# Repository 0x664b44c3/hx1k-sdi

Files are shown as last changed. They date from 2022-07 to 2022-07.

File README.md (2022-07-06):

# HX1k-SDI
An SDI encoder/serializer on Lattice iCE40 FPGAs

The iCE40 series of FPGAs is low cost and is supported by an opensource toolchain (though not currently used for this project)
The devices are low density and low speed and lack advanced features like SerDes or true LVDS-IO, though.

## Features of the serializer
 * fits multiple times into an 1k gates iCE40 FPGA
 * fpga-vendor agnostic, besides the specific instantiation of the SB_IO for DDR out
 * needs one PLL running at half the bitrate (or at full bitrate if your IO can run at 270MHz)
 * should be extendable to generate DVB-ASI (would need 8B/10B instead of SMPTE scrambler and NRZI)
 * accepts bt.656 video at 27MHz word rate

## Abstract
This project implements an SD-SDI serializer (aka transmitter) completely in fabric, requiring nothing but an unused PLL
that is used to generate a 135MHz from an externally supplied 27MHz sample clock (27MWords/s with CbYCrY 4:2:2 encoding, 
13.5MHz pixel clock).
Most of the logic operates at 27MHz with just the final multiplexer and a DDR-out buffer running at the full 135MHz.

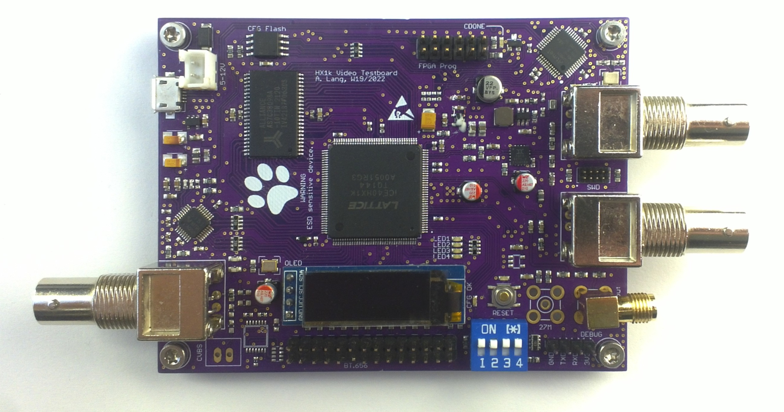
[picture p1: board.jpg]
board


## Features of the test board
 * iCE40HX1k FPGA
 * 27MHz crystal oscillator
 * 10bit bt.656 video port
 * TVP5151 video decoder to test analog to sdi conversion
   * alternatively/additionally an LMH1881 can be fitted
 * 1MByte (512kx16) of SRAM taht can hold one complete frame of interlaced PAL/NTCS
 * ATSAMD21G18 MCU for programming the FPGA config flash and configuring the TVP, can be omitted
 * 4-pin header for I2C 128x32 OLED display
 * FPGA config pins on pinheader to allow flashing the config without a MCU
 * switchmode regulator for the 3.3V rail, allows input voltages of 5 to 12V
* Current functionality in the FPGA demo project
   * Color bars generator
   * SDI pathological pattern generator
   * Analog to SDI converter
   * About half the FPGA is still free for additional functionality

## Scope
This project contains a complete eval board for SDI video generation on
iCE40-HX FPGAs. UP-series might work, too, but it's unclear if the IOB and Fabric are fast enaugh
(might test it on iCEBreaker at some point in time).

## Contents
This project consists of the following subfolders:
 * fpga: the FPGA design (VHDL, iCECube2 project)
 * hardware: The board design (eagle 6), schematic diagrams as PDF
 * firmware: Firmware for the ATSAMD21 MCU that is on the board as well
 * release: synthesized FPGA config, firmware image, gerbers etc

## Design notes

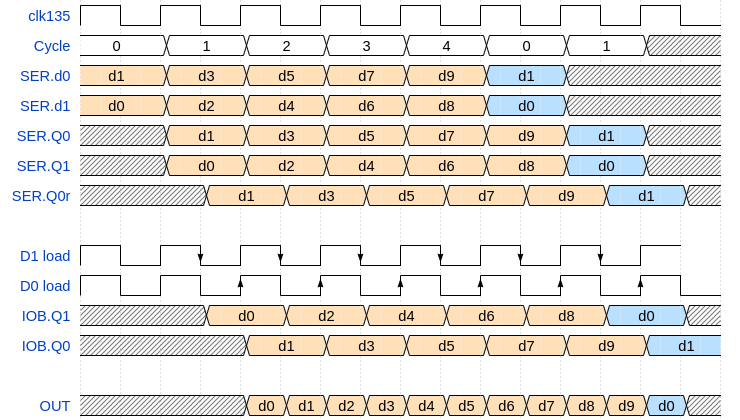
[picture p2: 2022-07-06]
documentation/timings.png

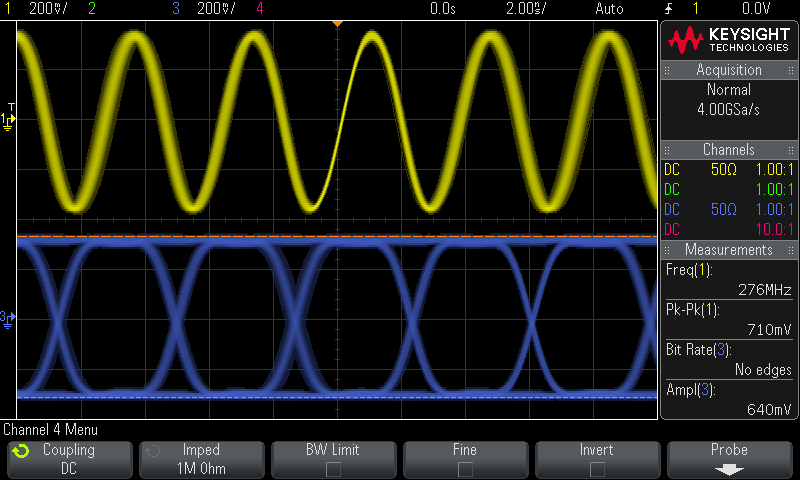
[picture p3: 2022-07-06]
documentation/sdi_eye.png

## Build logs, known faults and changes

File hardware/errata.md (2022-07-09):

# Errata
## Revision 0 (initial release)
 - RAM data pin 6 on global buffer pad that blocks PLL when used
 - footprint of IC7 (NCP115) should have slightly larger pads for easier soldering
 -

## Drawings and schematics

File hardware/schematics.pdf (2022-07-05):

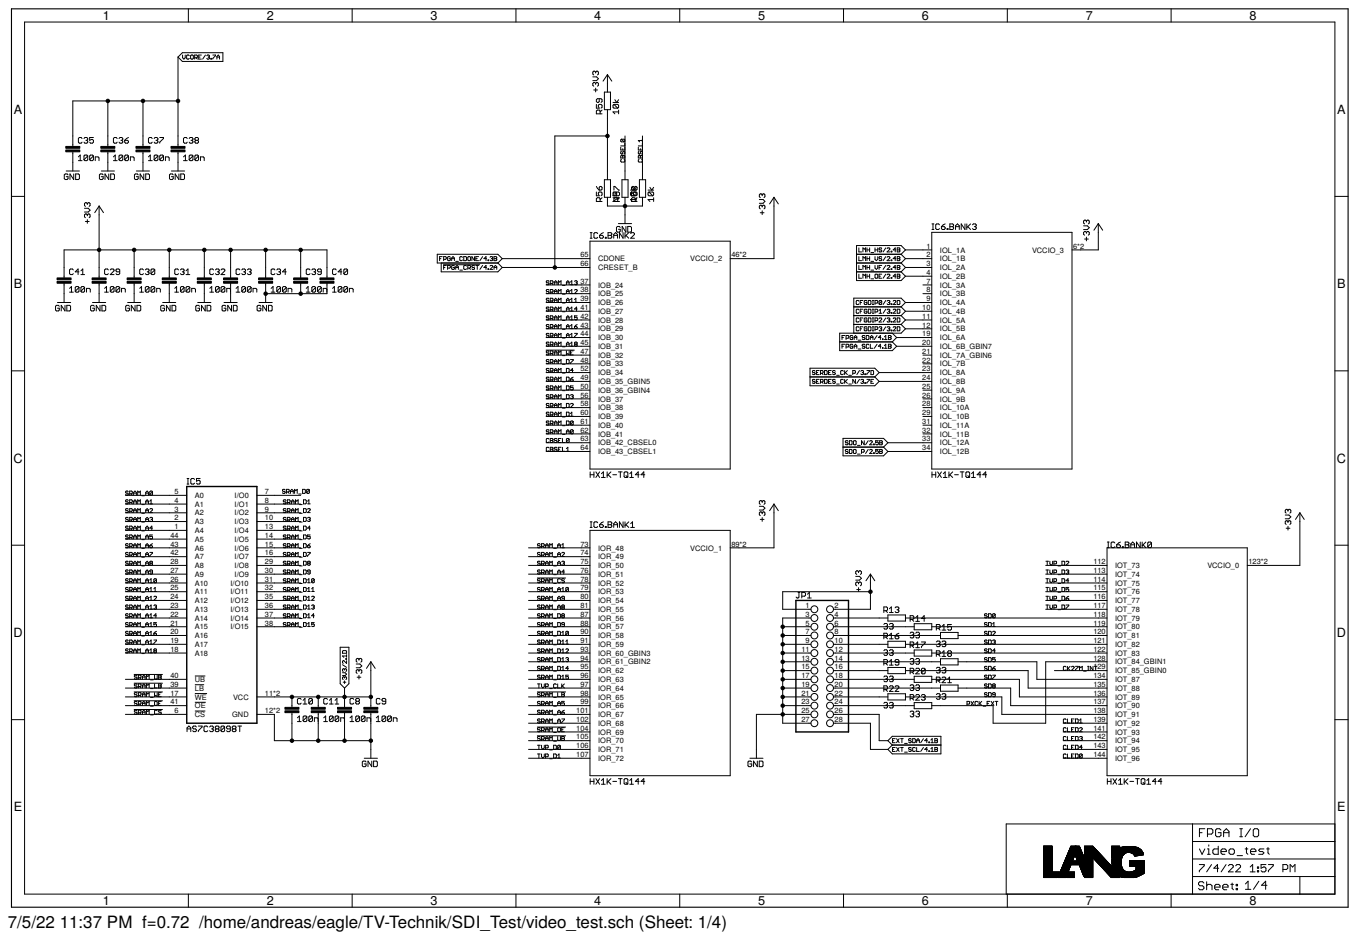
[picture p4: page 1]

7/5/22 11:37 PM f=0.72 /home/andreas/eagle/TV-Technik/SDI_Test/video_test.sch (Sheet: 1/4)

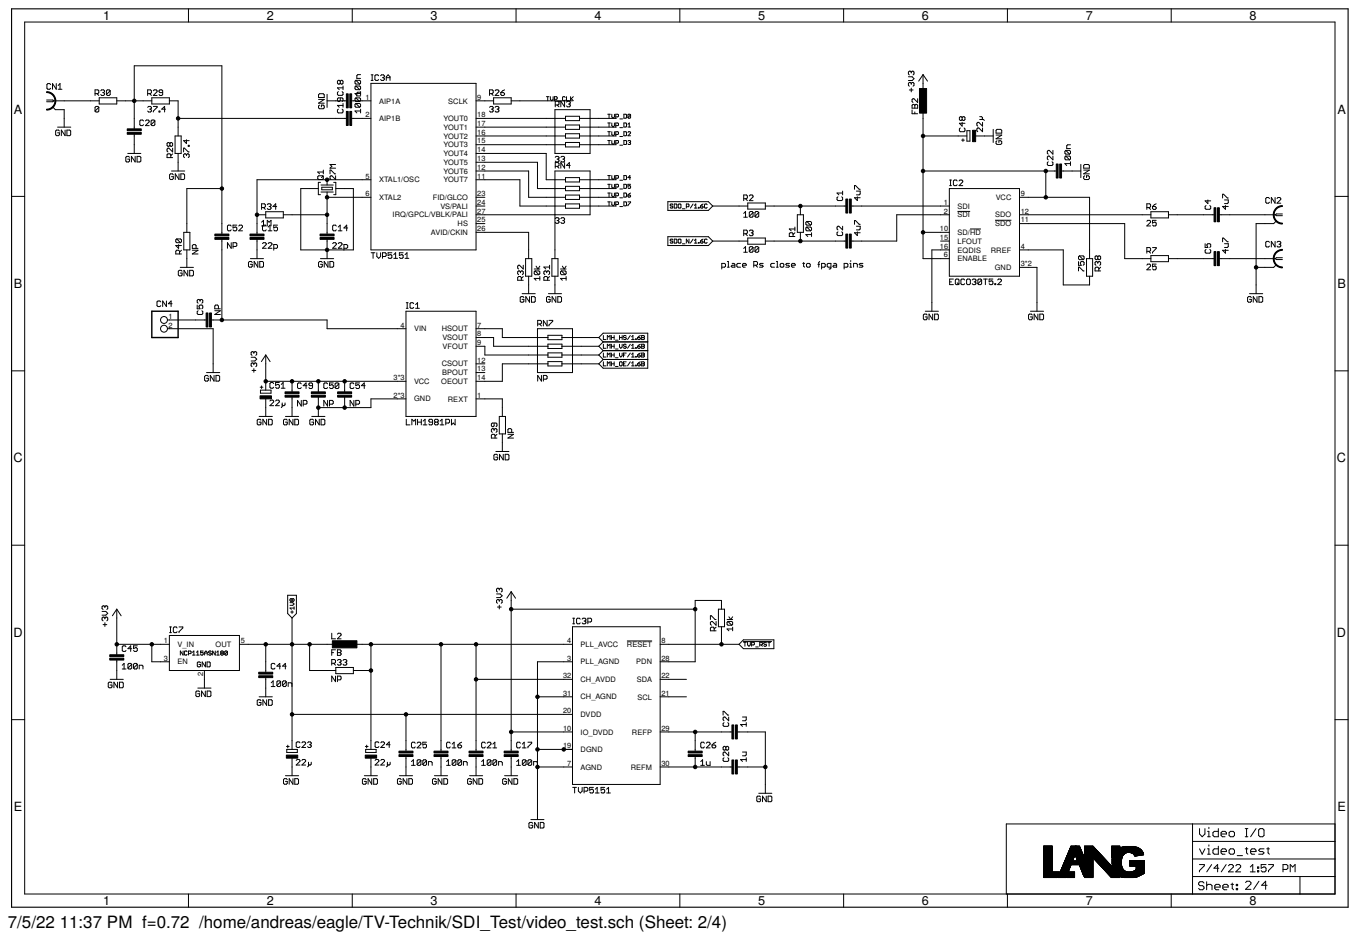
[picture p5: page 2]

7/5/22 11:37 PM f=0.72 /home/andreas/eagle/TV-Technik/SDI_Test/video_test.sch (Sheet: 2/4)

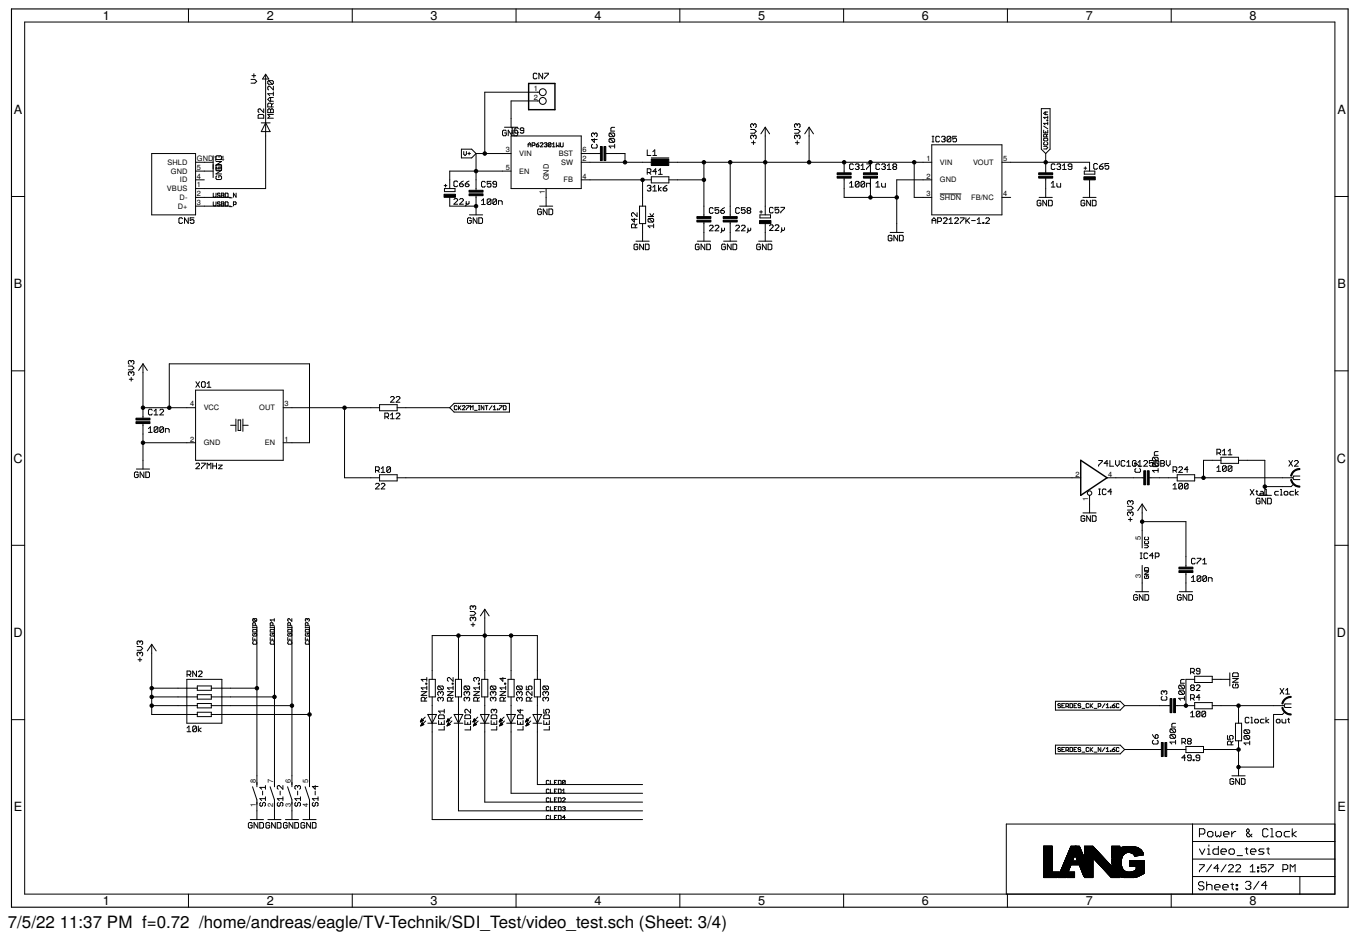
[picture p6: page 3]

7/5/22 11:37 PM f=0.72 /home/andreas/eagle/TV-Technik/SDI_Test/video_test.sch (Sheet: 3/4)

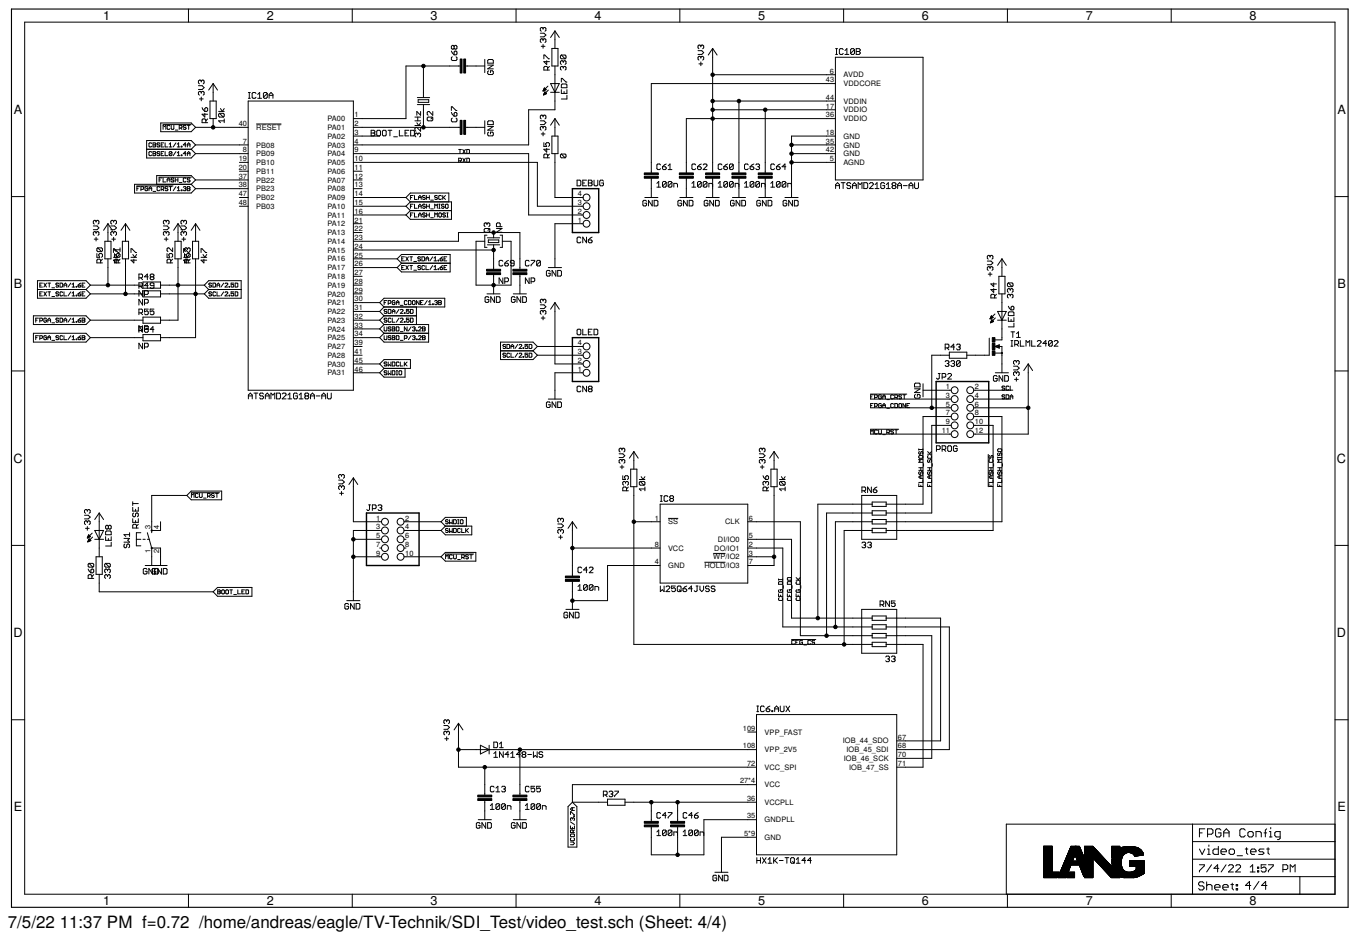
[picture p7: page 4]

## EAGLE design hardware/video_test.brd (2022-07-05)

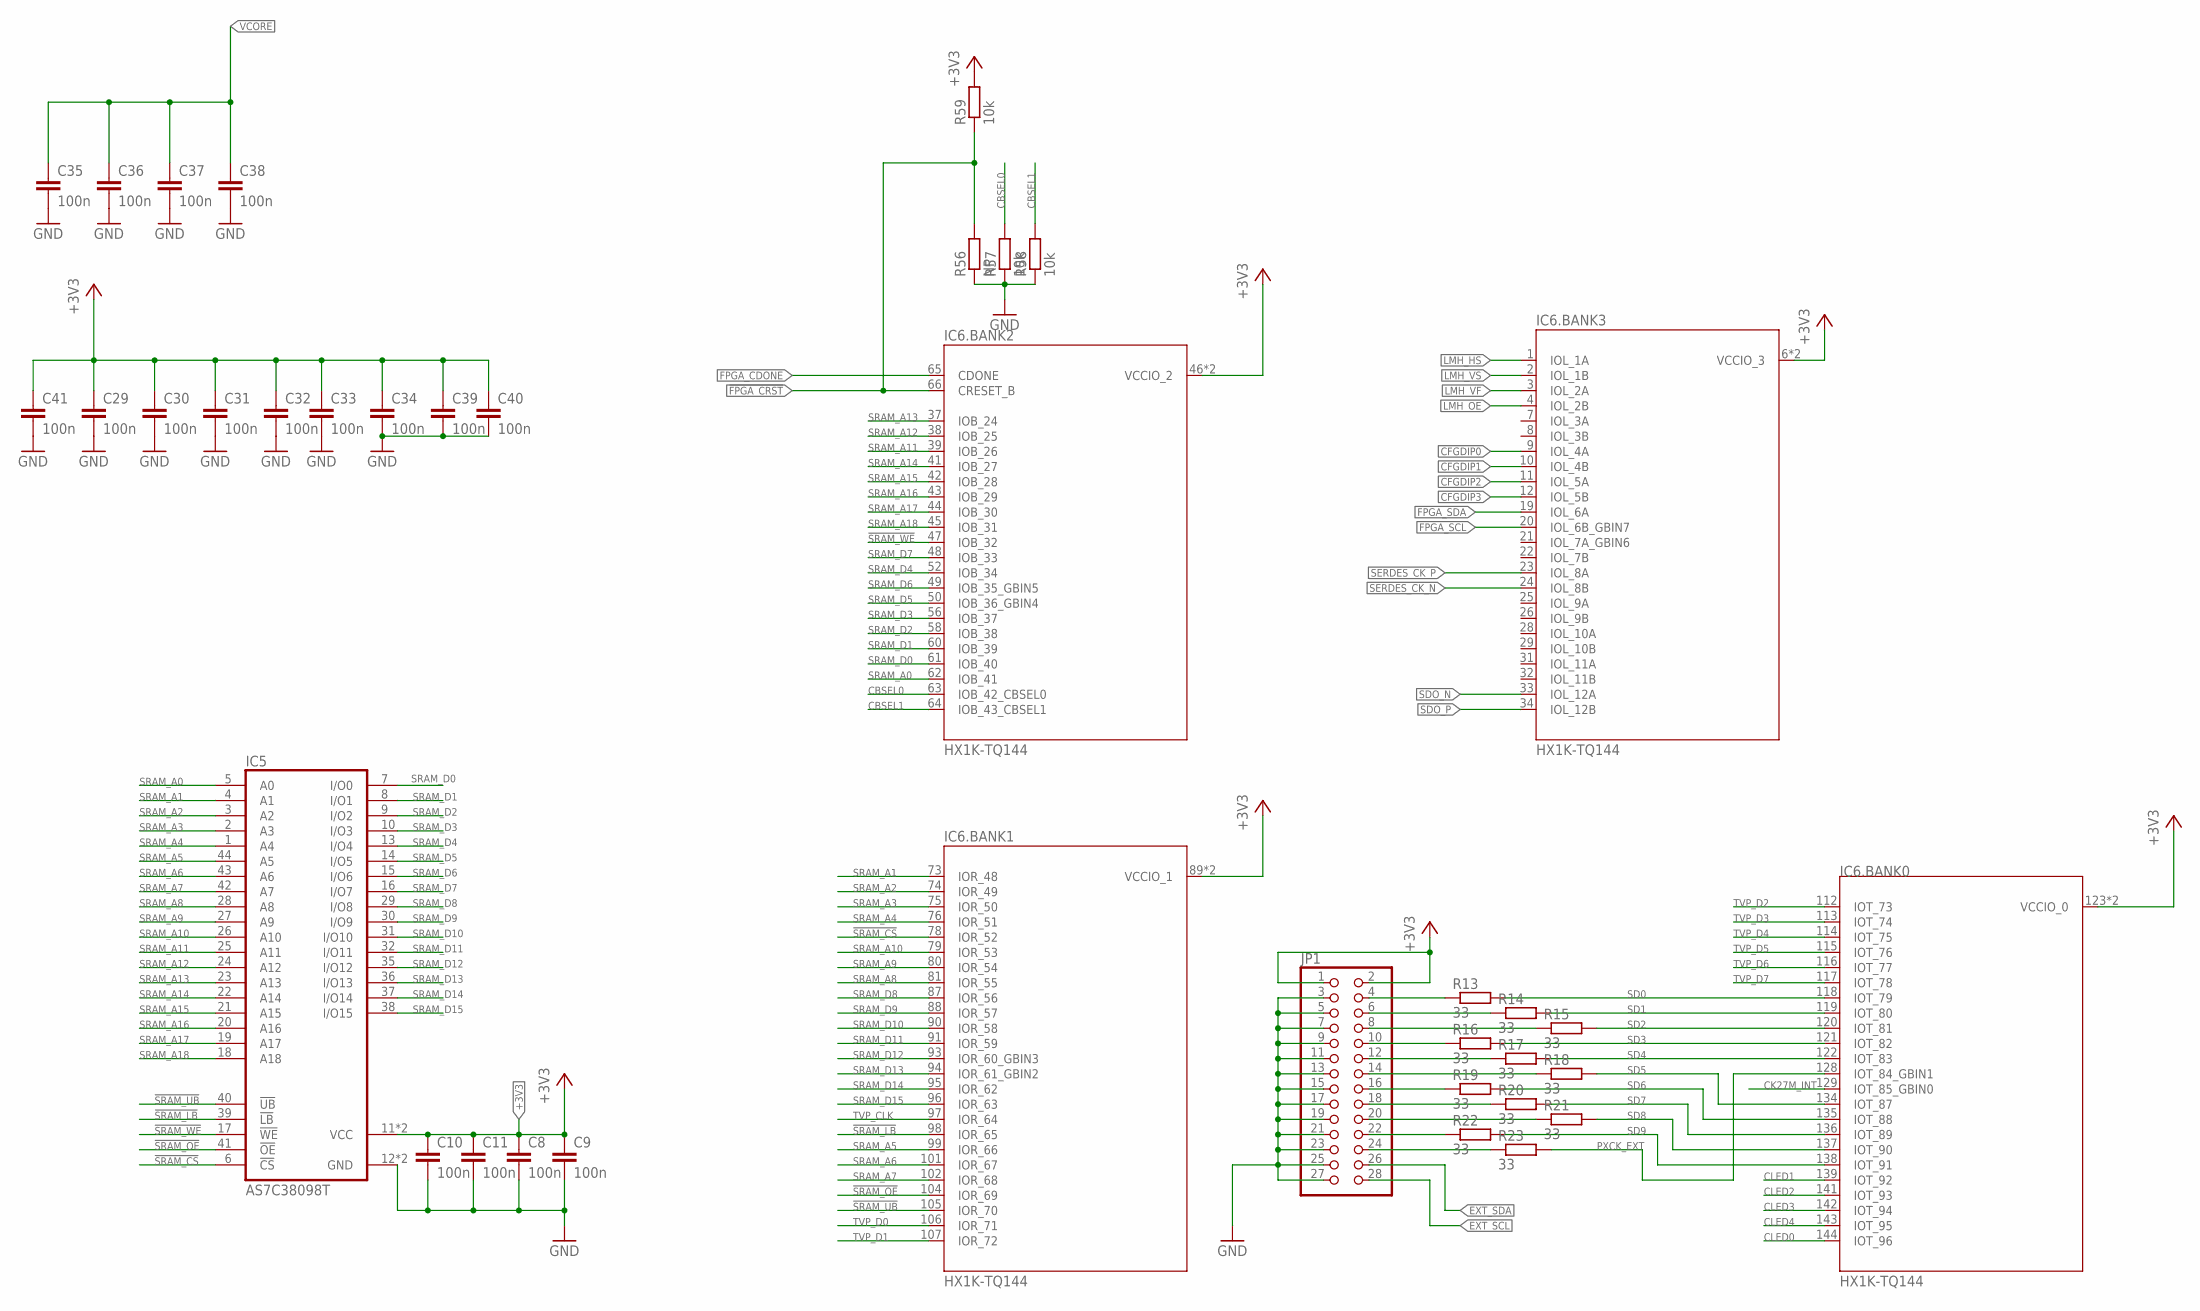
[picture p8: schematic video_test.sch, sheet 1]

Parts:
C8, C9: 100n; C0603
C10, C11, C29, C30, C31, C32, C33, C34, C35, C36, C37, C38, C39, C40, C41: 100n; C0402
IC5: AS7C38098T; TSOPII-Z44
IC6: HX1K-TQ144; QFP50P2200X2200X160-144N
JP1: PINHD-2X14; 2X14
R13, R14, R15, R16, R17, R18, R19, R20, R21, R22, R23: 33; R0603
R56: NP; R0402
R57, R58, R59: 10k; R0402

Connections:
!FPGA_CRST!: IC6.66 (CRESET_B), R56.2, R59.1; also elsewhere on the board
!SRAM_CS!: IC5.6 (!CS!), IC6.78 (IOR_52)
!SRAM_LB!: IC5.39 (!LB!), IC6.98 (IOR_65)
!SRAM_OE!: IC5.41 (!OE!), IC6.104 (IOR_69)
!SRAM_UB!: IC5.40 (!UB!), IC6.105 (IOR_70)
!SRAM_WE!: IC5.17 (!WE!), IC6.47 (IOB_32)
+3V3: C8.1, C9.1, C10.1, C11.1, C29.1, C30.1, C31.1, C32.1, C33.1, C34.1, C39.1, C40.1, C41.1, IC5.11 (VCC), IC5.33 (VCC), IC6.6 (VCCIO_3), IC6.30 (VCCIO_3), IC6.46 (VCCIO_2), IC6.57 (VCCIO_2), IC6.89 (VCCIO_1), IC6.100 (VCCIO_1), IC6.123 (VCCIO_0), IC6.133 (VCCIO_0), JP1.1, JP1.2, R59.2; also elsewhere on the board
CBSEL0: IC6.63 (IOB_42_CBSEL0), R57.2; also elsewhere on the board
CBSEL1: IC6.64 (IOB_43_CBSEL1), R58.2; also elsewhere on the board
CFGDIP0: IC6.9 (IOL_4A); also elsewhere on the board
CFGDIP1: IC6.10 (IOL_4B); also elsewhere on the board
CFGDIP2: IC6.11 (IOL_5A); also elsewhere on the board
CFGDIP3: IC6.12 (IOL_5B); also elsewhere on the board
CK27M_INT: IC6.129 (IOT_85_GBIN0); also elsewhere on the board
CLED0: IC6.144 (IOT_96); also elsewhere on the board
CLED1: IC6.139 (IOT_92); also elsewhere on the board
CLED2: IC6.141 (IOT_93); also elsewhere on the board
CLED3: IC6.142 (IOT_94); also elsewhere on the board
CLED4: IC6.143 (IOT_95); also elsewhere on the board
EXT_SCL: JP1.28; also elsewhere on the board
EXT_SDA: JP1.26; also elsewhere on the board
FPGA_CDONE: IC6.65 (CDONE); also elsewhere on the board
FPGA_SCL: IC6.20 (IOL_6B_GBIN7); also elsewhere on the board
FPGA_SDA: IC6.19 (IOL_6A); also elsewhere on the board
GND: C8.2, C9.2, C10.2, C11.2, C29.2, C30.2, C31.2, C32.2, C33.2, C34.2, C35.2, C36.2, C37.2, C38.2, C39.2, C40.2, C41.2, IC5.12 (GND), IC5.34 (GND), JP1.3, JP1.5, JP1.7, JP1.9, JP1.11, JP1.13, JP1.15, JP1.17, JP1.19, JP1.21, JP1.23, JP1.25, JP1.27, R56.1, R57.1, R58.1; also elsewhere on the board
LMH_HS: IC6.1 (IOL_1A); also elsewhere on the board
LMH_OE: IC6.4 (IOL_2B); also elsewhere on the board
LMH_VF: IC6.3 (IOL_2A); also elsewhere on the board
LMH_VS: IC6.2 (IOL_1B); also elsewhere on the board
unnamed: JP1.4, R13.1
unnamed: JP1.6, R14.1
unnamed: JP1.8, R15.1
unnamed: JP1.10, R16.1
unnamed: JP1.12, R17.1
unnamed: JP1.14, R18.1
unnamed: JP1.16, R19.1
unnamed: JP1.18, R20.1
unnamed: JP1.20, R21.1
unnamed: JP1.22, R22.1
unnamed: JP1.24, R23.1
PXCK_EXT: IC6.128 (IOT_84_GBIN1), R23.2
SD0: IC6.118 (IOT_79), R13.2
SD1: IC6.119 (IOT_80), R14.2
SD2: IC6.120 (IOT_81), R15.2
SD3: IC6.121 (IOT_82), R16.2
SD4: IC6.122 (IOT_83), R17.2
SD5: IC6.134 (IOT_87), R18.2
SD6: IC6.135 (IOT_88), R19.2
SD7: IC6.136 (IOT_89), R20.2
SD8: IC6.137 (IOT_90), R21.2
SD9: IC6.138 (IOT_91), R22.2
SDO_N: IC6.33 (IOL_12A); also elsewhere on the board
SDO_P: IC6.34 (IOL_12B); also elsewhere on the board
SERDES_CK_N: IC6.24 (IOL_8B); also elsewhere on the board
SERDES_CK_P: IC6.23 (IOL_8A); also elsewhere on the board
SRAM_A0: IC5.5 (A0), IC6.62 (IOB_41)
SRAM_A1: IC5.4 (A1), IC6.73 (IOR_48)
SRAM_A2: IC5.3 (A2), IC6.74 (IOR_49)
SRAM_A3: IC5.2 (A3), IC6.75 (IOR_50)
SRAM_A4: IC5.1 (A4), IC6.76 (IOR_51)
SRAM_A5: IC5.44 (A5), IC6.99 (IOR_66)
SRAM_A6: IC5.43 (A6), IC6.101 (IOR_67)
SRAM_A7: IC5.42 (A7), IC6.102 (IOR_68)
SRAM_A8: IC5.28 (A8), IC6.81 (IOR_55)
SRAM_A9: IC5.27 (A9), IC6.80 (IOR_54)
SRAM_A10: IC5.26 (A10), IC6.79 (IOR_53)
SRAM_A11: IC5.25 (A11), IC6.39 (IOB_26)
SRAM_A12: IC5.24 (A12), IC6.38 (IOB_25)
SRAM_A13: IC5.23 (A13), IC6.37 (IOB_24)
SRAM_A14: IC5.22 (A14), IC6.41 (IOB_27)
SRAM_A15: IC5.21 (A15), IC6.42 (IOB_28)
SRAM_A16: IC5.20 (A16), IC6.43 (IOB_29)
SRAM_A17: IC5.19 (A17), IC6.44 (IOB_30)
SRAM_A18: IC5.18 (A18), IC6.45 (IOB_31)
SRAM_D0: IC5.7 (I/O0), IC6.61 (IOB_40)
SRAM_D1: IC5.8 (I/O1), IC6.60 (IOB_39)
SRAM_D2: IC5.9 (I/O2), IC6.58 (IOB_38)
SRAM_D3: IC5.10 (I/O3), IC6.56 (IOB_37)
SRAM_D4: IC5.13 (I/O4), IC6.52 (IOB_34)
SRAM_D5: IC5.14 (I/O5), IC6.50 (IOB_36_GBIN4)
SRAM_D6: IC5.15 (I/O6), IC6.49 (IOB_35_GBIN5)
SRAM_D7: IC5.16 (I/O7), IC6.48 (IOB_33)
SRAM_D8: IC5.29 (I/O8), IC6.87 (IOR_56)
SRAM_D9: IC5.30 (I/O9), IC6.88 (IOR_57)
SRAM_D10: IC5.31 (I/O10), IC6.90 (IOR_58)
SRAM_D11: IC5.32 (I/O11), IC6.91 (IOR_59)
SRAM_D12: IC5.35 (I/O12), IC6.93 (IOR_60_GBIN3)
SRAM_D13: IC5.36 (I/O13), IC6.94 (IOR_61_GBIN2)
SRAM_D14: IC5.37 (I/O14), IC6.95 (IOR_62)
SRAM_D15: IC5.38 (I/O15), IC6.96 (IOR_63)
TVP_CLK: IC6.97 (IOR_64); also elsewhere on the board
TVP_D0: IC6.106 (IOR_71); also elsewhere on the board
TVP_D1: IC6.107 (IOR_72); also elsewhere on the board
TVP_D2: IC6.112 (IOT_73); also elsewhere on the board
TVP_D3: IC6.113 (IOT_74); also elsewhere on the board
TVP_D4: IC6.114 (IOT_75); also elsewhere on the board
TVP_D5: IC6.115 (IOT_76); also elsewhere on the board
TVP_D6: IC6.116 (IOT_77); also elsewhere on the board
TVP_D7: IC6.117 (IOT_78); also elsewhere on the board
VCORE: C35.1, C36.1, C37.1, C38.1; also elsewhere on the board
VPP_FAST: IC6.109 (VPP_FAST)

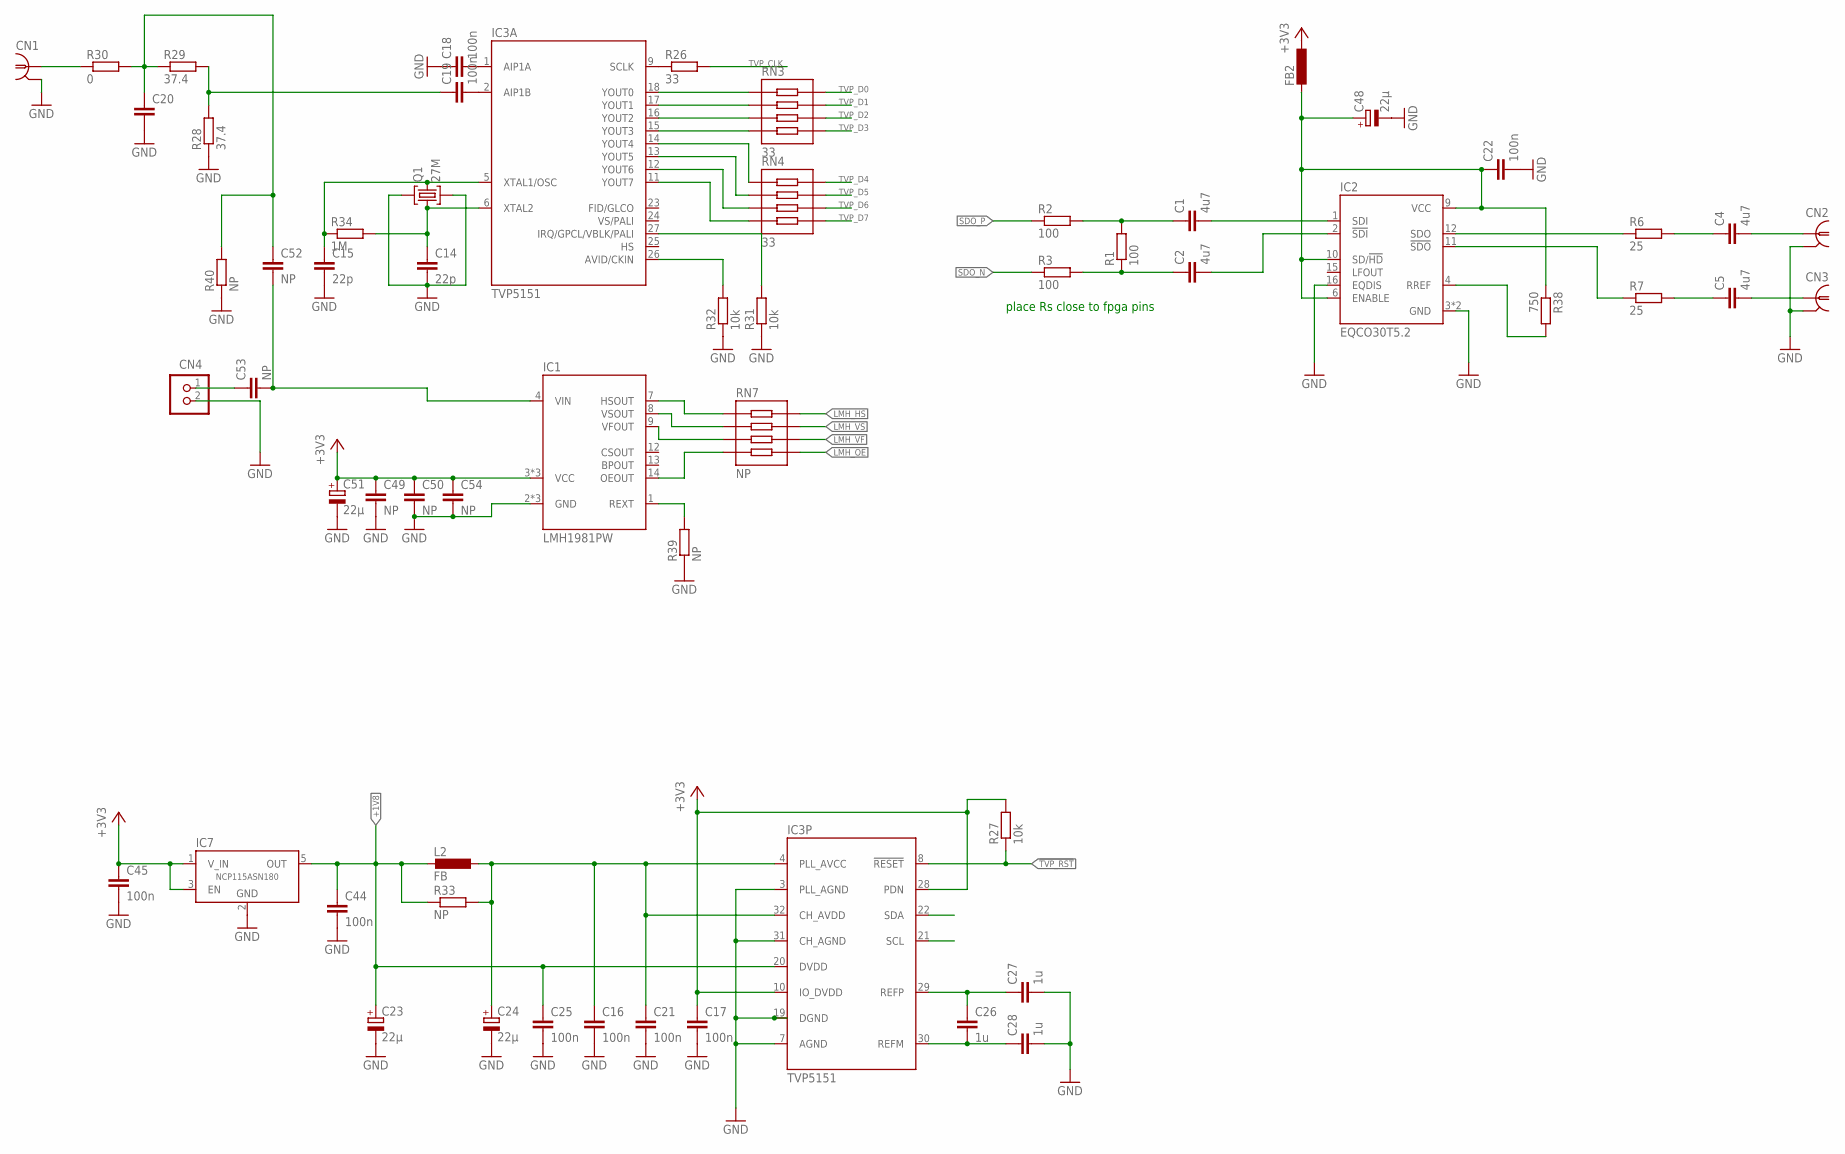
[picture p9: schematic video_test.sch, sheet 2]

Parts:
C1, C2, C4, C5: 4u7; C0603
C14, C15: 22p; C0603
C16, C17, C18, C19, C21, C22, C25: 100n; C0402
C20: C-EUC0603; C0603
C23, C24: 22µ; B/3528-21R
C26, C27, C28: 1u; C0603
C44, C45: 100n; C0603
C48, C51: 22µ; PANASONIC_B
C49, C50, C54: NP; C0402
C52, C53: NP; C0603
CN1, CN2, CN3: BU-BNC-RA; AMP_227161
CN4: JST-XH2; B2B-XH
FB2: L-EU_L0603; R0603
IC1: LMH1981PW; TSSOP14
IC2: EQCO30T5.2; QFN16_065
IC3: TVP5151; SPQFP32
IC7: NCP115ASN180; SOT23-5
L2: FB; R0805
Q1: 27M; MT
R1, R2, R3: 100; R0603
R6, R7: 25; R0603
R26: 33; R0603
R27, R31, R32: 10k; R0402
R28, R29: 37.4; R0603
R30: 0; R0603
R33, R39, R40: NP; R0603
R34: 1M; R0603
R38: 750; R0603
RN3, RN4: 33; CTS742C083
RN7: NP; CTS742C083

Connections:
!TVP_RST!: IC3.8 (!RESET!), R27.1
+1V8: C23.+, C25.1, C44.1, IC3.20 (DVDD), IC7.5 (OUT), L2.2, R33.1
+1V8_A: C16.1, C21.1, C24.+, IC3.4 (PLL_AVCC), IC3.32 (CH_AVDD), L2.1, R33.2
+3V3: C17.1, C45.1, C49.1, C50.1, C51.+, C54.1, FB2.1, IC1.3 (VCC), IC1.6 (VCC), IC1.11 (VCC), IC3.10 (IO_DVDD), IC3.28 (PDN), IC7.1 (V_IN), IC7.3 (EN), R27.2; also elsewhere on the board
GND: C14.2, C15.2, C16.2, C17.2, C18.1, C20.2, C21.2, C22.2, C23.-, C24.-, C25.2, C27.2, C28.2, C44.2, C45.2, C48.-, C49.2, C50.2, C51.-, C54.2, CN1.2 (GND), CN2.2 (GND), CN3.2 (GND), CN4.2, IC1.2 (GND), IC1.5 (GND), IC1.10 (GND), IC2.3 (GND), IC2.16 (EQDIS), IC2.TP (GND), IC3.3 (PLL_AGND), IC3.7 (AGND), IC3.19 (DGND), IC3.31 (CH_AGND), IC7.2 (GND), Q1.2 (G1), Q1.4 (G2), R28.1, R31.1, R32.1, R39.1, R40.1; also elsewhere on the board
LMH_HS: RN7.8 (B1); also elsewhere on the board
LMH_OE: RN7.5 (B4); also elsewhere on the board
LMH_VF: RN7.6 (B3); also elsewhere on the board
LMH_VS: RN7.7 (B2); also elsewhere on the board
unnamed: C1.2, IC2.1 (SDI)
unnamed: C2.2, IC2.2 (!SDI!)
unnamed: C2.1, R1.1, R3.2
unnamed: C1.1, R1.2, R2.2
unnamed: C4.1, R6.2
unnamed: C5.1, R7.2
unnamed: C4.2, CN2.1
unnamed: C5.2, CN3.1
unnamed: C22.1, C48.+, FB2.2, IC2.6 (ENABLE), IC2.9 (VCC), IC2.10 (SD/!HD!), R38.1
unnamed: IC2.4 (RREF), R38.2
unnamed: C15.1, IC3.5 (XTAL1/OSC), Q1.3 (2), R34.1
unnamed: C14.1, IC3.6 (XTAL2), Q1.1, R34.2
unnamed: C26.1, C27.1, IC3.29 (REFP)
unnamed: C26.2, C28.1, IC3.30 (REFM)
unnamed: C18.2, IC3.1 (AIP1A)
unnamed: IC3.11 (YOUT7), RN4.4 (A4)
unnamed: IC1.7 (HSOUT), RN7.1 (A1)
unnamed: IC3.9 (SCLK), R26.1
unnamed: IC3.12 (YOUT6), RN4.3 (A3)
unnamed: IC3.13 (YOUT5), RN4.2 (A2)
unnamed: IC3.14 (YOUT4), RN4.1 (A1)
unnamed: IC3.15 (YOUT3), RN3.4 (A4)
unnamed: IC3.16 (YOUT2), RN3.3 (A3)
unnamed: IC3.17 (YOUT1), RN3.2 (A2)
unnamed: IC3.18 (YOUT0), RN3.1 (A1)
unnamed: C19.2, IC3.2 (AIP1B)
unnamed: IC3.27 (IRQ/GPCL/VBLK/PALI), R31.2
unnamed: C19.1, R28.2, R29.2
unnamed: C20.1, C52.1, R29.1, R30.2, R40.2
unnamed: CN1.1, R30.1
unnamed: IC3.26 (AVID/CKIN), R32.2
unnamed: C52.2, C53.2, IC1.4 (VIN)
unnamed: C53.1, CN4.1
unnamed: IC1.8 (VSOUT), RN7.2 (A2)
unnamed: IC1.1 (REXT), R39.2
unnamed: IC1.9 (VFOUT), RN7.3 (A3)
unnamed: IC1.14 (OEOUT), RN7.4 (A4)
SCL: IC3.21 (SCL); also elsewhere on the board
SDA: IC3.22 (SDA); also elsewhere on the board
SDI_OUT_N: IC2.11 (!SDO!), R7.1
SDI_OUT_P: IC2.12 (SDO), R6.1
SDO_N: R3.1; also elsewhere on the board
SDO_P: R2.1; also elsewhere on the board
TVP_CLK: R26.2; also elsewhere on the board
TVP_D0: RN3.8 (B1); also elsewhere on the board
TVP_D1: RN3.7 (B2); also elsewhere on the board
TVP_D2: RN3.6 (B3); also elsewhere on the board
TVP_D3: RN3.5 (B4); also elsewhere on the board
TVP_D4: RN4.8 (B1); also elsewhere on the board
TVP_D5: RN4.7 (B2); also elsewhere on the board
TVP_D6: RN4.6 (B3); also elsewhere on the board
TVP_D7: RN4.5 (B4); also elsewhere on the board

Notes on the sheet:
place Rs close to fpga pins

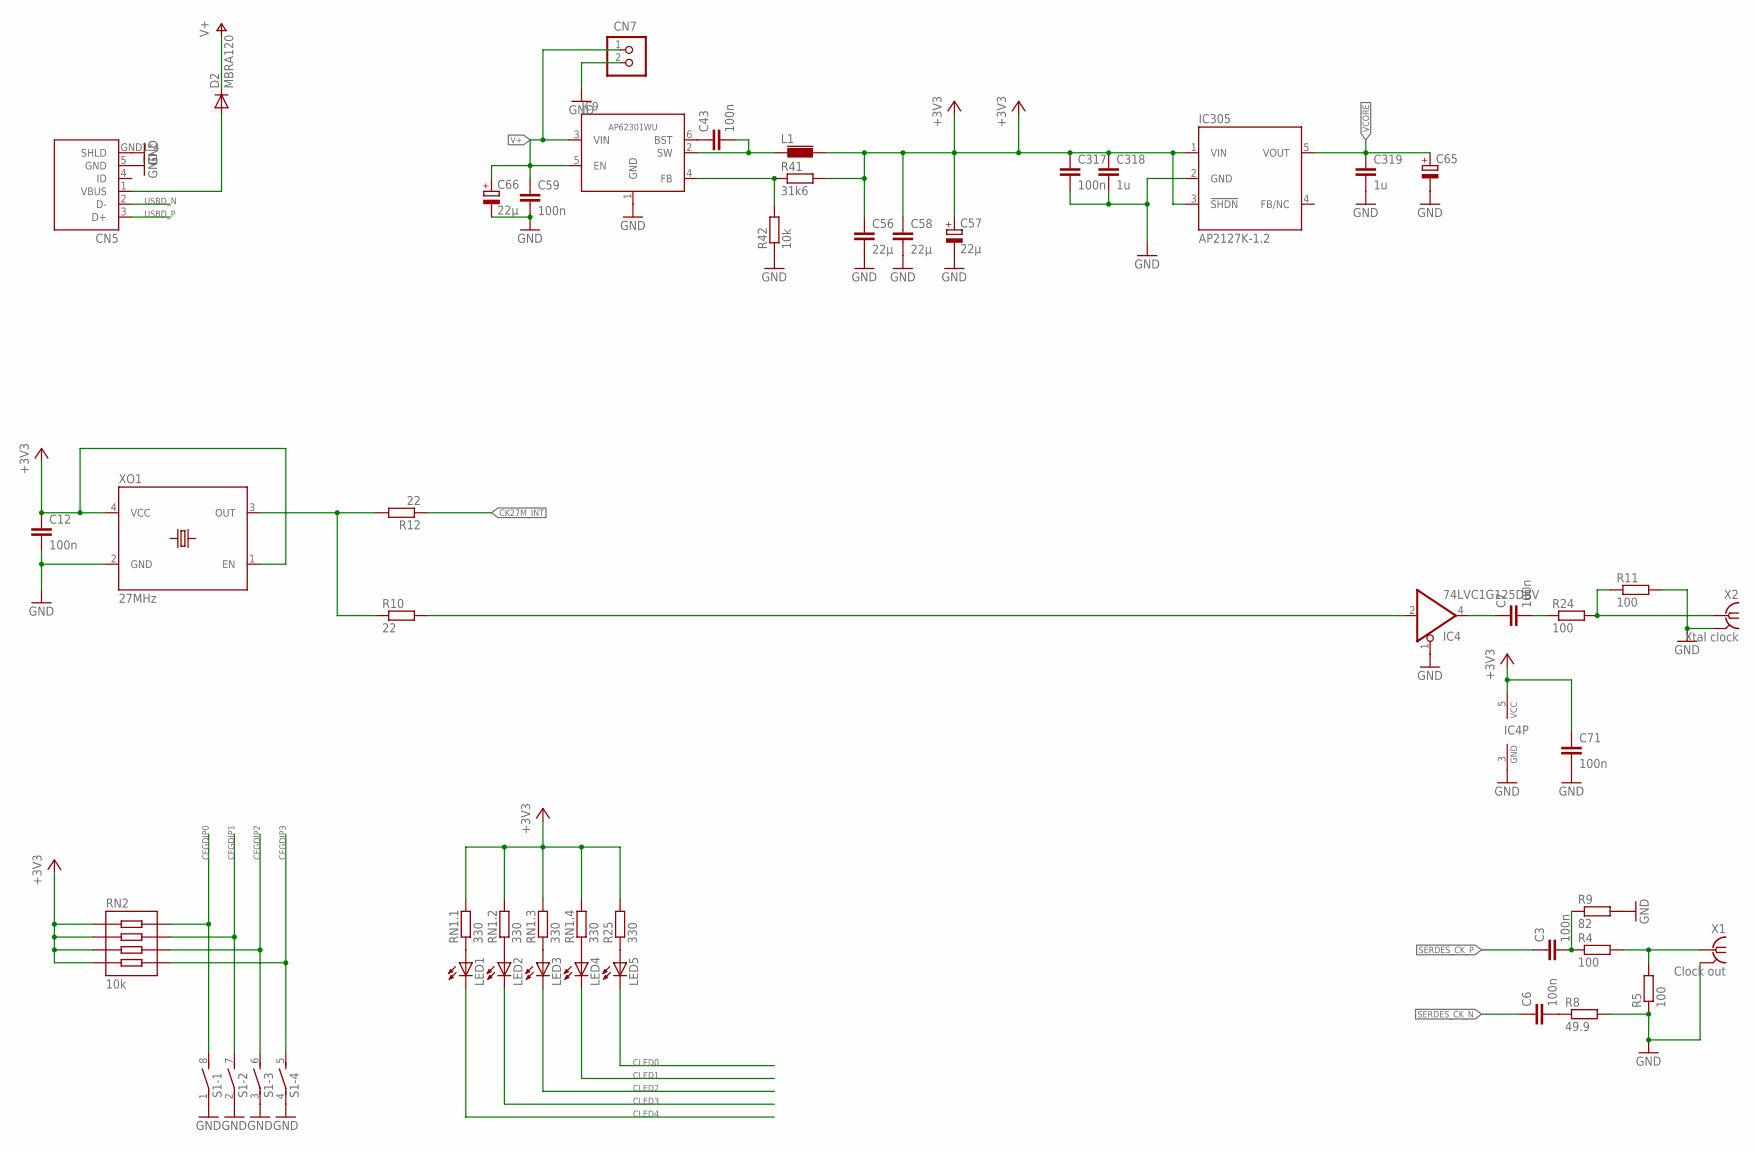
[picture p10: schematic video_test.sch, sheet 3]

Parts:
C3, C6, C7, C12, C43, C59, C71, C317: 100n; C0603
C56, C58: 22µ; C0805
C57: 22µ; PANASONIC_B
C65: CPOL-EUB/3528-21R; B/3528-21R
C66: 22µ; PANASONIC_C
C318, C319: 1u; C0603
CN5: USB-UJ2-MIBH-G; UJ2-MIBH-G-SMT
CN7: JST-XH2; B2B-XH
D2: MBRA120; SMA
IC4: 74LVC1G125DBV; SOT23-5
IC9: AP62301WU; SOT23-6L
IC305: AP2127K-1.2; SOT23-5
L1: L-TYA4020; TYA4020
LED1, LED2, LED3, LED4, LED5: LEDCHIP-LED0603; CHIP-LED0603
R4, R5, R11, R24: 100; R0603
R8: 49.9; R0603
R9: 82; R0603
R10, R12: 22; R0603
R25: 330; R0603
R41: 31k6; R0603
R42: 10k; R0603
RN1: 330; CTS742C083
RN2: 10k; CTS742C083
S1: DIP04S
X1: Clock out; BU-SMA-V
X2: Xtal clock; BU-SMA-V
XO1: 27MHz; ECS-2333

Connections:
+3V3: C12.1, C56.1, C57.+, C58.1, C71.1, C317.1, C318.1, IC4.5 (VCC), IC305.1 (VIN), IC305.3 (!SHDN!), L1.2, R25.2, R41.2, RN1.5 (2), RN1.6 (2), RN1.7 (2), RN1.8 (2), RN2.1 (A1), RN2.2 (A2), RN2.3 (A3), RN2.4 (A4), XO1.1 (EN), XO1.4 (VCC); also elsewhere on the board
CFGDIP0: RN2.8 (B1), S1.8 (2); also elsewhere on the board
CFGDIP1: RN2.7 (B2), S1.7 (2); also elsewhere on the board
CFGDIP2: RN2.6 (B3), S1.6 (2); also elsewhere on the board
CFGDIP3: RN2.5 (B4), S1.5 (2); also elsewhere on the board
CK27M_INT: R12.1; also elsewhere on the board
CLED0: LED5.C; also elsewhere on the board
CLED1: LED4.C; also elsewhere on the board
CLED2: LED3.C; also elsewhere on the board
CLED3: LED2.C; also elsewhere on the board
CLED4: LED1.C; also elsewhere on the board
GND: C12.2, C56.2, C57.-, C58.2, C59.2, C65.-, C66.-, C71.2, C317.2, C318.2, C319.2, CN5.5 (GND), CN5.GND1 (SHLD), CN5.GND2 (SHLD), CN5.GND3 (SHLD), CN5.GND4 (SHLD), CN7.2, IC4.1 (OE), IC4.3 (GND), IC9.1 (GND), IC305.2 (GND), R5.1, R8.2, R9.2, R11.2, R42.1, S1.1, S1.2 (1), S1.3 (1), S1.4 (1), X1.2 (GND), X1.3 (GND), X1.4 (GND), X1.5 (GND), X2.2 (GND), X2.3 (GND), X2.4 (GND), X2.5 (GND), XO1.2 (GND); also elsewhere on the board
unnamed: R4.2, R5.2, X1.1
unnamed: C6.2, R8.1
unnamed: C3.2, R4.1, R9.1
unnamed: R11.1, R24.2, X2.1
unnamed: IC4.2 (I), R10.2
unnamed: R10.1, R12.2, XO1.3 (OUT)
unnamed: C7.1, IC4.4 (O)
unnamed: C7.2, R24.1
unnamed: C43.2, IC9.2 (SW), L1.1
unnamed: LED1.A, RN1.1
unnamed: LED2.A, RN1.2 (1)
unnamed: LED3.A, RN1.3 (1)
unnamed: LED4.A, RN1.4 (1)
unnamed: LED5.A, R25.1
unnamed: C43.1, IC9.6 (BST)
unnamed: IC9.4 (FB), R41.1, R42.2
unnamed: CN5.1 (VBUS), D2.A
SERDES_CK_N: C6.1; also elsewhere on the board
SERDES_CK_P: C3.1; also elsewhere on the board
USBD_N: CN5.2 (D-); also elsewhere on the board
USBD_P: CN5.3 (D+); also elsewhere on the board
V+: C59.1, C66.+, CN7.1, D2.C, IC9.3 (VIN), IC9.5 (EN)
VCORE: C65.+, C319.1, IC305.5 (VOUT); also elsewhere on the board

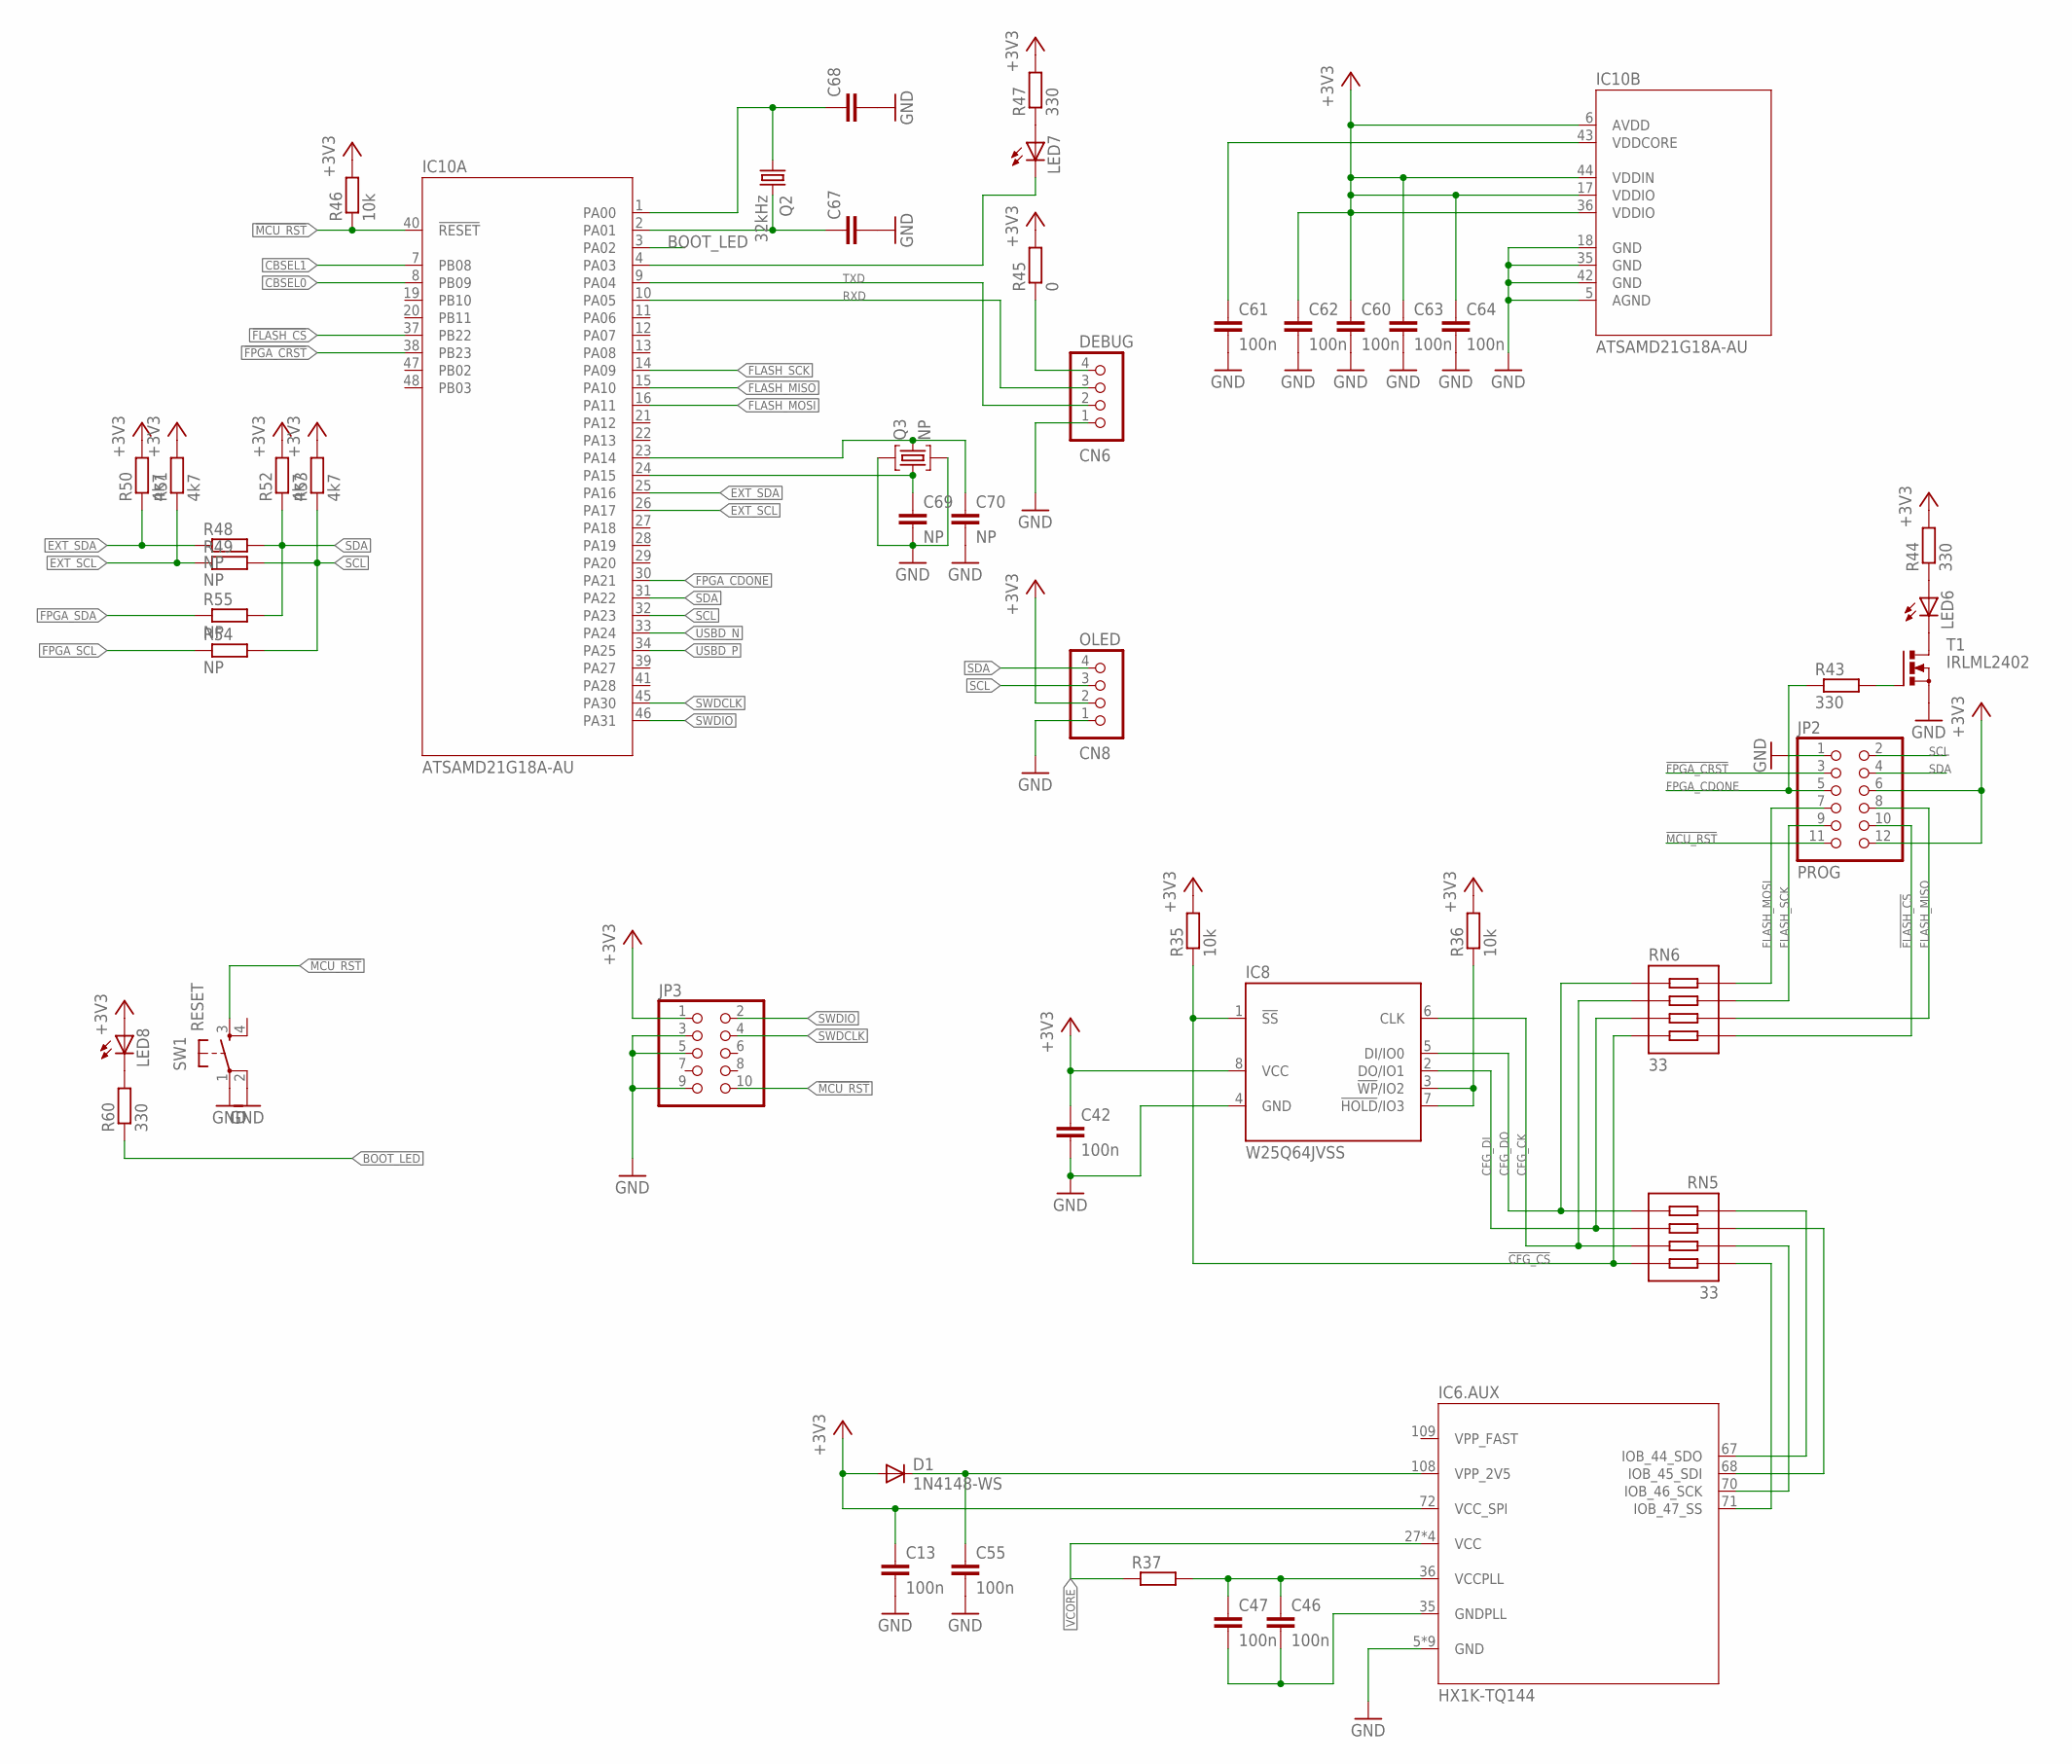
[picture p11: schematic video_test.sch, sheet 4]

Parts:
C13, C46, C55, C60, C61, C62, C63, C64: 100n; C0402
C42, C47: 100n; C0603
C67, C68: C-EUC0402; C0402
C69, C70: NP; C0603
CN6: DEBUG; SL-254-RH-4
CN8: OLED; SL-254-RH-4
D1: 1N4148-WS; SOD323
IC6: HX1K-TQ144; QFP50P2200X2200X160-144N
IC8: W25Q64JVSS; SO-08M
IC10: ATSAMD21G18A-AU; TQFP48_7X7MC_MCH
JP2: PROG; 2X06
JP3: PINHD-2X5-127; SL127-2X5
LED6, LED7, LED8: LEDCHIP-LED0603; CHIP-LED0603
Q2: 32kHz; IQXC-25
Q3: NP; MT
R35, R36, R46: 10k; R0603
R37: R-EU_R0603; R0603
R43, R44, R47, R60: 330; R0603
R45: 0; R0603
R48, R49: NP; R0603
R50, R51, R52, R53: 4k7; R0603
R54, R55: NP; R0402
RN5, RN6: 33; CTS742C083
SW1: RESET; PTS526
T1: IRLML2402; SOT23

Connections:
!CFG_CS!: IC8.1 (!SS!), R35.1, RN5.5 (B4), RN6.4 (A4)
!FLASH_CS!: IC10.37 (PB22), JP2.10, RN6.5 (B4)
!FPGA_CRST!: IC10.38 (PB23), JP2.3; also elsewhere on the board
!MCU_RST!: IC10.40 (!RESET), JP2.11, JP3.10, R46.1, SW1.3 (S)
+3V3: C13.1, C42.1, C60.1, C62.1, C63.1, C64.1, CN8.2, D1.A, IC6.72 (VCC_SPI), IC8.8 (VCC), IC10.6 (AVDD), IC10.17 (VDDIO), IC10.36 (VDDIO), IC10.44 (VDDIN), JP2.6, JP2.12, JP3.1, LED8.A, R35.2, R36.2, R44.2, R45.2, R46.2, R47.2, R50.2, R51.2, R52.2, R53.2; also elsewhere on the board
BOOT_LED: IC10.3 (PA02), R60.1
CBSEL0: IC10.8 (PB09); also elsewhere on the board
CBSEL1: IC10.7 (PB08); also elsewhere on the board
CFG_CK: IC8.6 (CLK), RN5.6 (B3), RN6.2 (A2)
CFG_DI: IC8.2 (DO/IO1), RN5.7 (B2), RN6.3 (A3)
CFG_DO: IC8.5 (DI/IO0), RN5.8 (B1), RN6.1 (A1)
EXT_SCL: IC10.26 (PA17), R49.1, R51.1; also elsewhere on the board
EXT_SDA: IC10.25 (PA16), R48.1, R50.1; also elsewhere on the board
FLASH_MISO: IC10.15 (PA10), JP2.8, RN6.6 (B3)
FLASH_MOSI: IC10.16 (PA11), JP2.7, RN6.8 (B1)
FLASH_SCK: IC10.14 (PA09), JP2.9, RN6.7 (B2)
FPGA_CDONE: IC10.30 (PA21), JP2.5, R43.1; also elsewhere on the board
FPGA_CS: IC6.71 (IOB_47_SS), RN5.4 (A4)
FPGA_SCK: IC6.70 (IOB_46_SCK), RN5.3 (A3)
FPGA_SCL: R54.1; also elsewhere on the board
FPGA_SDA: R55.1; also elsewhere on the board
FPGA_SDI: IC6.68 (IOB_45_SDI), RN5.2 (A2)
FPGA_SDO: IC6.67 (IOB_44_SDO), RN5.1 (A1)
GND: C13.2, C42.2, C55.2, C60.2, C61.2, C62.2, C63.2, C64.2, C67.2, C68.2, C69.2, C70.2, CN6.1, CN8.1, IC6.5 (GND), IC6.13 (GND), IC6.14 (GND), IC6.59 (GND), IC6.69 (GND), IC6.86 (GND), IC6.103 (GND), IC6.132 (GND), IC6.140 (GND), IC8.4 (GND), IC10.5 (AGND), IC10.18 (GND), IC10.35 (GND), IC10.42 (GND), JP2.1, JP3.3, JP3.5, JP3.9, Q3.2 (G1), Q3.4 (G2), SW1.1, SW1.2 (P1), T1.2 (S); also elsewhere on the board
GNDPLL: C46.2, C47.2, IC6.35 (GNDPLL)
unnamed: C55.1, D1.K (C), IC6.108 (VPP_2V5)
unnamed: IC8.3 (!WP!/IO2), IC8.7 (!HOLD!/IO3), R36.1
unnamed: LED6.C, T1.3 (D)
unnamed: R43.2, T1.1 (G)
unnamed: LED6.A, R44.1
unnamed: C67.1, IC10.2 (PA01), Q2.2
unnamed: C61.1, IC10.43 (VDDCORE)
unnamed: CN6.4, R45.1
unnamed: C68.1, IC10.1 (PA00), Q2.1
unnamed: C69.1, IC10.24 (PA15), Q3.1
unnamed: C70.1, IC10.23 (PA14), Q3.3 (2)
unnamed: LED7.A, R47.1
unnamed: IC10.4 (PA03), LED7.C
unnamed: LED8.C, R60.2
RXD: CN6.3, IC10.10 (PA05)
SCL: CN8.3, IC10.32 (PA23), JP2.2, R49.2, R53.1, R54.2; also elsewhere on the board
SDA: CN8.4, IC10.31 (PA22), JP2.4, R48.2, R52.1, R55.2; also elsewhere on the board
SWDCLK: IC10.45 (PA30), JP3.4
SWDIO: IC10.46 (PA31), JP3.2
TXD: CN6.2, IC10.9 (PA04)
USBD_N: IC10.33 (PA24); also elsewhere on the board
USBD_P: IC10.34 (PA25); also elsewhere on the board
VCCPLL: C46.1, C47.1, IC6.36 (VCCPLL), R37.2
VCORE: IC6.27 (VCC), IC6.51 (VCC), IC6.92 (VCC), IC6.111 (VCC), R37.1; also elsewhere on the board
VPP_FAST: IC6.109 (VPP_FAST)

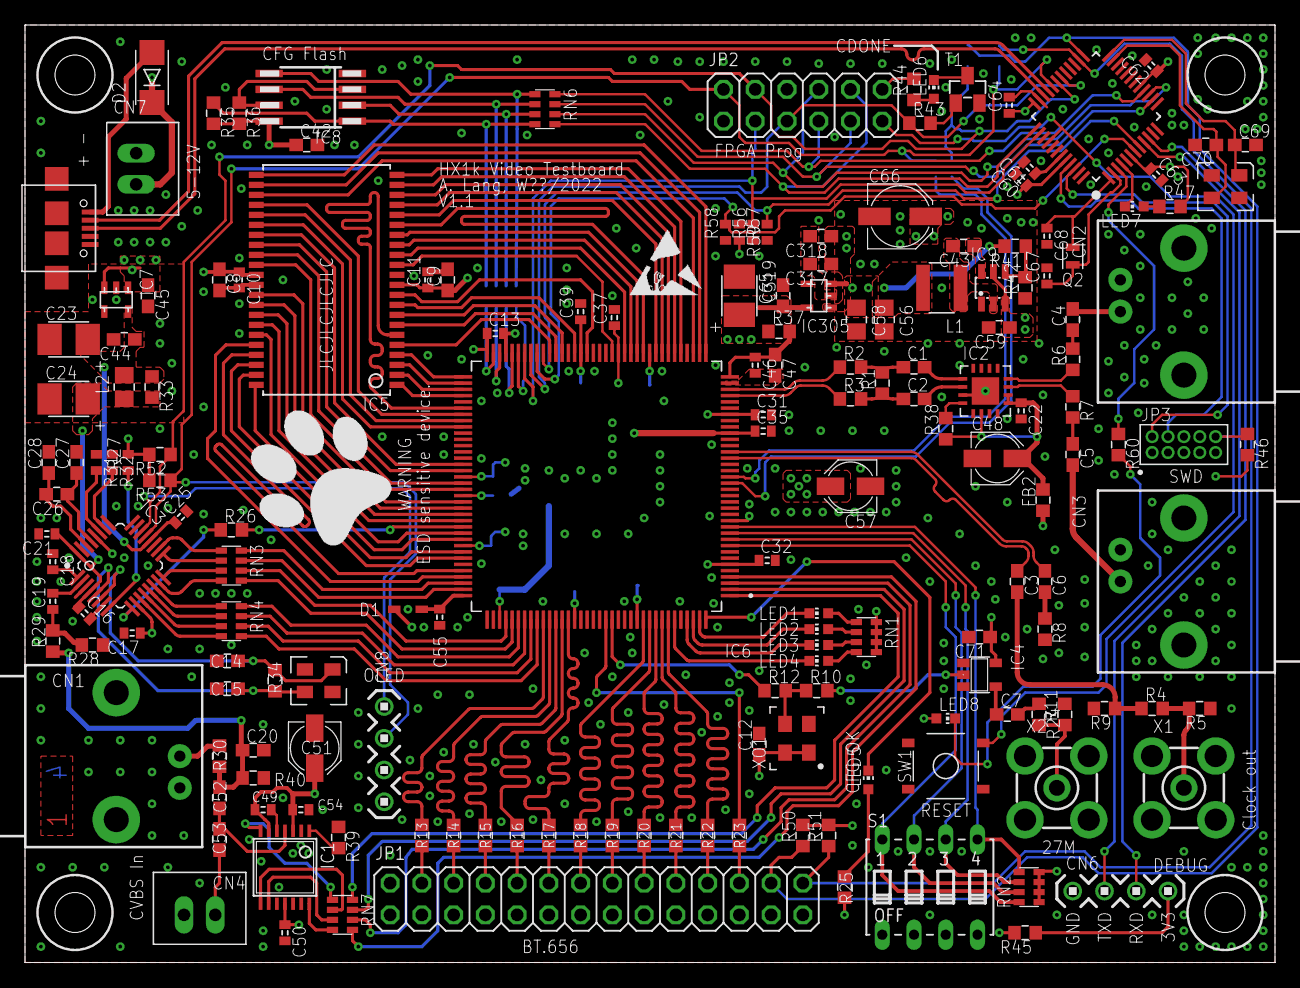
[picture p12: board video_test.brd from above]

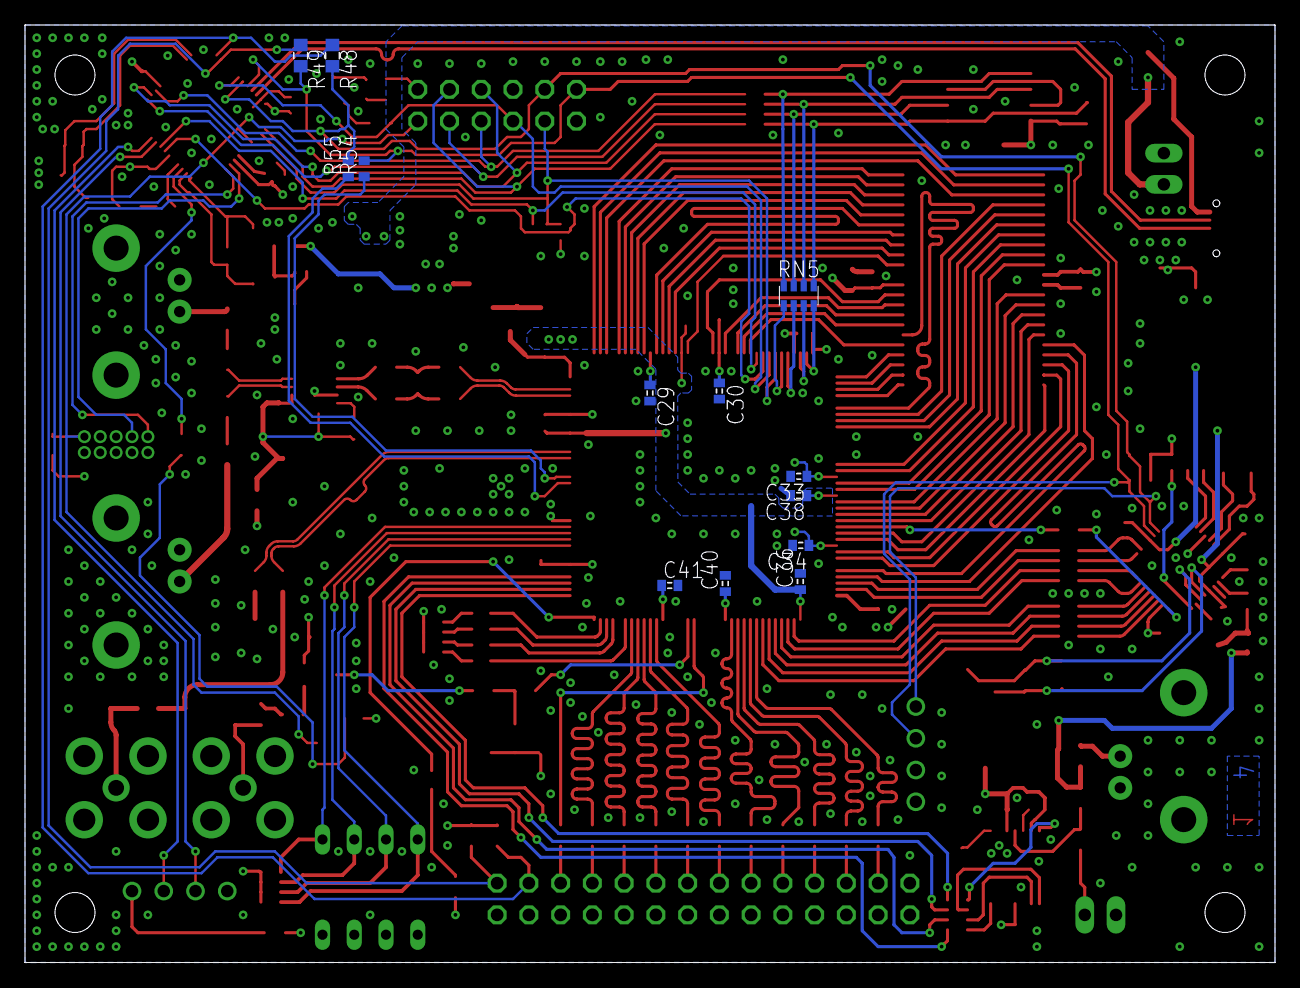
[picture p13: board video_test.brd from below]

Board: 4 copper layers, 100.0 x 75.0 mm, 185 parts (13 on the bottom side), 198 nets.

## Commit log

2022-07-05 added hardware source files
    [video_test.brd, video_test.sch]
2022-07-05 Added schematics pdf and initial fpga bitstream
2022-07-05 added image of the pcb
2022-07-05 update schematics pdf (only contained first page)
2022-07-08 better board photo

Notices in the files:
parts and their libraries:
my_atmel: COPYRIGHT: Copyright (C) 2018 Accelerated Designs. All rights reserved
